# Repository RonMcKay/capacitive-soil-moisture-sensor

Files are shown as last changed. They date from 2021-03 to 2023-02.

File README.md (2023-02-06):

<div align="center">

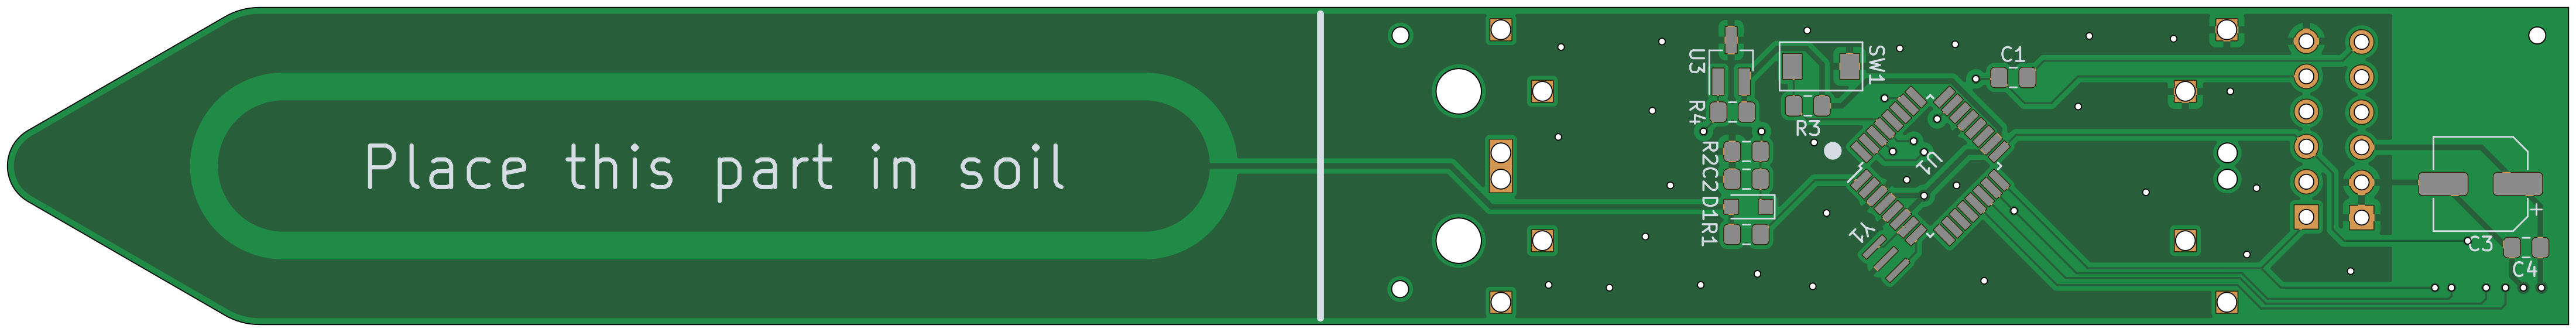
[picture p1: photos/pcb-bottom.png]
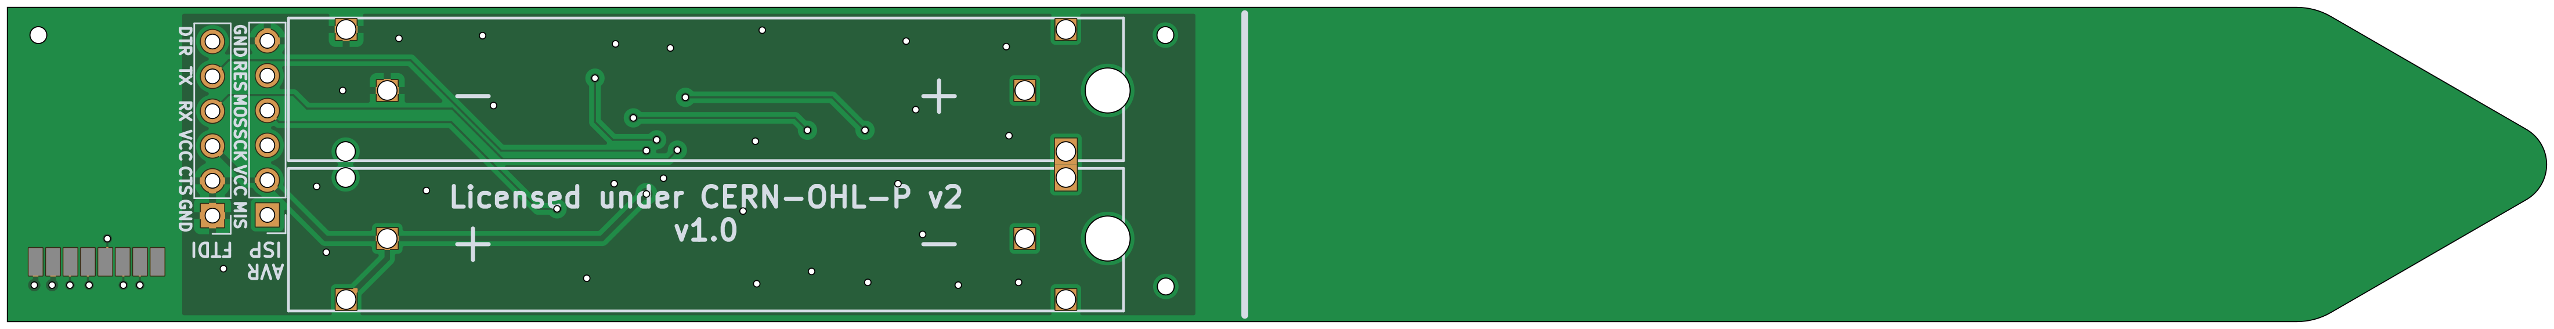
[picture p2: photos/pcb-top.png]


    

# Capacitive Soil Moisture Sensor

</div>

This is a capacitive soil moisture sensor which runs with a standalone ATmega328P and utilizes the [MySensors][1] framework.
It can however be adapted to any other framework that uses 2.4 GHz radio communication with an NRF24L01 if you upload your own code.

A short summary of the features is:
* Runs on 2 AAA batteries
* Sleeping current of 8uA (approx. 10 years of battery life under optimal conditions)
* Uses an NRF24L01 radio module for communication
* Utilizes an ATSHA204A for secure message signing (optional)
* A sensor value range of approximately 400 (from air to water)
* External 8MHz resonator for better temperature stability than the internal oscillator
* All SMD components (except the NRF24L01 radio) on one side of the pcb
* FTDI and AVR ISP connector for programming and bootloader burning
* 3D printable case

**Note: Take care when inserting the batteries as there is no reverse polarity protection on this board. Also check the pin assignment of the FTDI and AVR ISP headers as these might be non standard to save some space.**

# Table of Contents

- [Getting Started](#getting-started)
    - [Requirements](#requirements)
- [Hardware](#hardware)
    - [PCB Production](#pcb-production)
    - [Assembly](#assembly)
    - [Case](#case)
- [Software](#software)
    - [Calibration](#calibration)
- [Future Improvements](#future-improvements)
- [Contributing](#contributing)
- [License](#license)
- [Special Thanks to](#special-thanks-to)
- [Photos](#photos)

# Getting Started

If you want to work on the repository you just have to run:

    git clone --recurse-submodules https://github.com/RonMcKay/capacitive-soil-moisture-sensor

The PCB design is done in KiCad 6. You are pretty much good to go if you open the project with KiCad.

For programming and burning the bootloader I use [Visual Studio Code](https://code.visualstudio.com/)
together with [PlatformIO](https://platformio.org/) and [MiniCore](https://github.com/MCUdude/MiniCore)
(which is already included in the platform io plugin for vs code).

You can generate production/documentation files and run ERC/DRC tests by running `make` in the root directory. All production files are then placed under the hardware directory. The Makefile utilizes [docker](https://www.docker.com/) containers so you should have docker installed.

## Requirements

When working on the project you need the following installed locally and available in the development environment:

- Docker (for generating documentation and production files)
- KiCad 6 (for working on the PCB)
- Openscad (for generating the case)

# Hardware

## PCB Production

In recent years the DIY PCB industry segment has been growing and thus there are numerous options to quite easily order your boards online for low prices. Just download the Gerber-files from the [release page](https://github.com/RonMcKay/capacitive-soil-moisture-sensor/releases) or clone the repository and generate them yourself by running `make`.

## Assembly

For the assembly of your boards there are currently no SMT assembly files supplied with the release, although there are pick and place files for JLCPCB generated by `make` they are not yet optimized or tested, so use them at your own risk. For manual assembly you can find the BOM attached to the release as well as a nice interactive HTML BOM which eases component placement. You only need to take care that the two battery holders which are closest to the radio module do not touch each other as this would cause a short. To be really safe you can bend them away from each other.

**Note:** The ATSHA204A on the board is an optional component. If you do not want to assemble the board with it, you can leave it away together with the accompanying resistor.

## Case

You can find the STL files for a case attached to the release. If you want to tweak the tolerances for your printer or add additional features like printed on version or venting holes you can edit the `hardware/case/case.scad` file and generate the STLs by yourself by running `make case` in the root directory of the repository. The STL files are then placed under `hardware/case`.

# Software

## Calibration

The minimum (air) and maximum (water) sensor values need to be calibrated. For this, get a glass of water and flash the sensor with `#define CALIBRATION_MODE`. While reading out the log messages of the sensor, note down the sensor values for air and submerged in water. Change `AIR_SENSOR_VALUE` and `WATER_SENSOR_VALUE` accordingly and reflash the sensor after commenting out `#define CALIBRATION_MODE`. Your soil moisture sensor is now ready for operation.

# Future Improvements

Here is a list of possible future improvements that might be worth looking into:

* Make the sensor more compact by using a single AA/AAA battery together with a voltage booster
* Changing out the ATmega328P and the NRF24L01 for an NRF52.
* Some temperature readings of the soil would be awesome, like an SMD thermistor or something similar at the tip of the sensor.

Any contributions are highly welcome and I am happy to discuss remarks in the [github discussion section](https://github.com/RonMcKay/capacitive-soil-moisture-sensor/discussions).

# Contributing

I am happy to discuss and accept improvements on the project. Please make all your pull-requests against `master`. It is also a good idea to discuss your planned changes in the [github discussion section](https://github.com/RonMcKay/capacitive-soil-moisture-sensor/discussions) to avoid unnecessary work.

# License

This project is licensed under the CERN-OHL-P v2

# Special Thanks to

* [MySensors Team][1], which made me start creating my own IoT hardware
* miceuz, for his [long writeup](https://wemakethings.net/2012/09/26/capacitance_measurement/) of how capacitive soil moisture sensing is working
* Ken Shirriff, who's post about the [secrets of arduino PWM](http://www.righto.com/2009/07/secrets-of-arduino-pwm.html) made me understand the topic to a certain extend
* Everyone out there who is producing open source hardware and/or guides explaining the topic, which makes the diy electronics topic more accessible

P.S.: The sensor on the photos is only a prototype where I accidentally soldered some wrong value capacitor and forgot a capacitor for the FTDI connector. These are however already fixed in the pcb design.

# Photos

<div align="center">

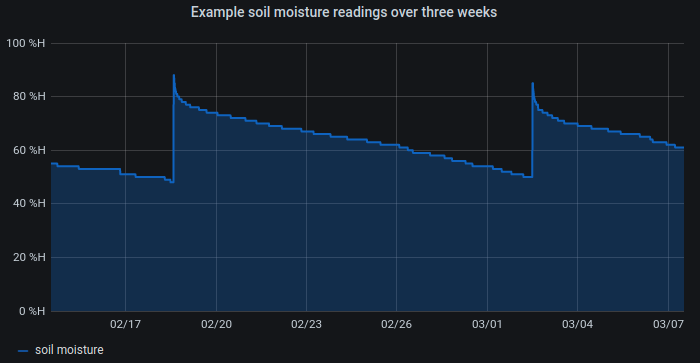
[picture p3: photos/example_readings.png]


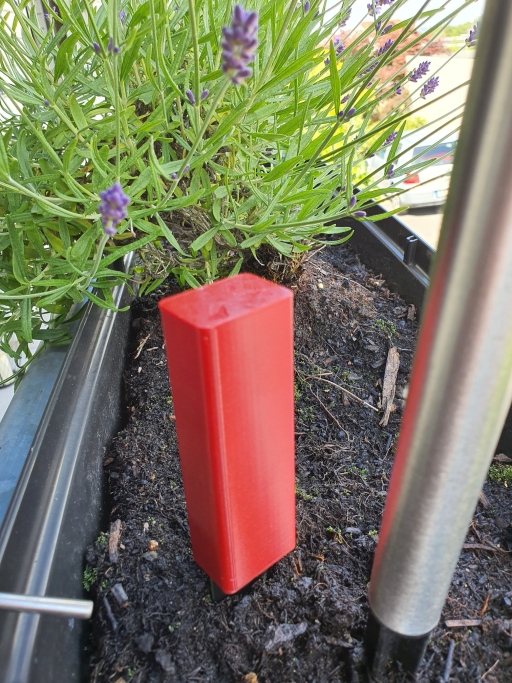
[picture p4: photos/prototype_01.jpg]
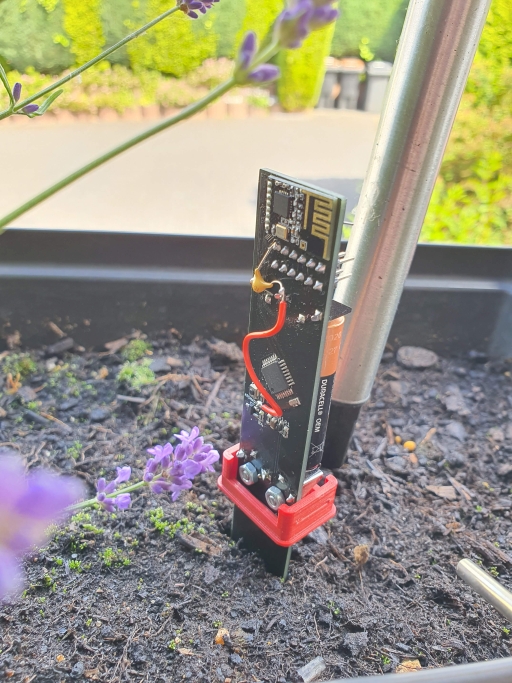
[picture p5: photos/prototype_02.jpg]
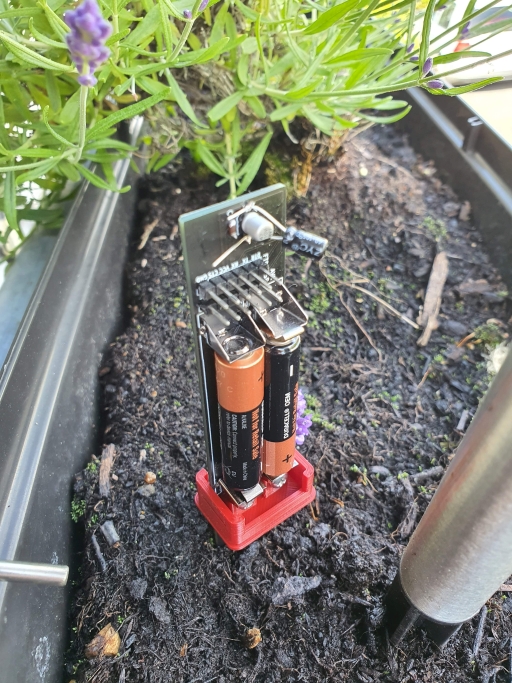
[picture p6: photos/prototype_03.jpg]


[1]: https://www.mysensors.org

</div>

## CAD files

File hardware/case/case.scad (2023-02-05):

$fn=50;

// General
part="all";
release_version="";

// Tolerances
tol=0.15;  // Tolerance for all measurements that need to fit, like screw hole diameter, PCB thickness, etc...
press_fit_tol=0.1;  // Tolerance between the shell and the base

// Wall thicknesses
wall_thickness=0.9;
base_thickness=1.2;

// Text
text_depth=0.5;

// Venting holes
venting_holes=false;
venting_hole_count=5;
venting_hole_dia=2;

// Case dimensions
height=82;  // height of the hole case measured from the center of the mounting screw holes
rim_thickness=2;
rim_height=10;

// Hardware
screw_hole_dia=3;
screw_hole_center_to_post_top = 3.5;
screw_length=10;
nut_thickness=2.4;

// PCB Settings
pcb_thickness=1.6;
pcb_top_depth=10.5;  // space in the case on the top side of the pcb
pcb_bottom_depth=max(2.5, nut_thickness);  // space in the case on the bottom side of the pcb
pcb_width=23.1;
mount_center_from_edge_1=6.1;  // distance to center of left mounting hole when viewed from the top
mount_center_from_edge_2=6.1;  // distance to center of right mounting hole when viewed from the top

// Mounting posts
post_width = 8.3;  // width of the mounting posts
post_height = 10;  // height of the mounting posts
post_depth = max(5, screw_length - pcb_bottom_depth - pcb_thickness - 2 * tol);

// Miscellaneous
fillet_radius=3;

// helper variables
inner_width=pcb_width + 2 * tol;
inner_depth=pcb_top_depth + pcb_bottom_depth + pcb_thickness + 2 * tol;
total_width=inner_width + 2 * wall_thickness + 2 * press_fit_tol + 2 * rim_thickness;
total_depth=inner_depth + 2 * wall_thickness + 2 * press_fit_tol + 2 * rim_thickness;
total_shell_height=height + (post_height - screw_hole_center_to_post_top);

// Edge for the interlocking between shell and base
lock_edge_depth=0.4;
lock_edge_length=inner_depth + 2 * rim_thickness - 2 * (fillet_radius - wall_thickness + press_fit_tol) - 3;

// Locking Edge
module lock_edge(depth=lock_edge_depth, length=lock_edge_length){
    translate([0, -length / 2, depth]) rotate([-90, 0, 0]) linear_extrude(length)
        polygon(points = [[0,0], [depth, depth], [0, 2 * depth]]);
}

// Mount Post
// `pos` is center of bottom front edge
module mounting_post(
    pos=[0, 0, 0],
    width=post_width,
    depth=post_depth,
    height=post_height,
){
    translate(pos - [width / 2, 0, 0])
        difference(){
            cube([width, depth, height]);
            translate([width / 2, -tol, height - screw_hole_center_to_post_top])
                rotate([-90, 0, 0])
                    cylinder(h=depth + 2 * tol, d=screw_hole_dia + 2 * tol);
        };
}

// Base
if(part == "base" || part == "all"){
    difference(){
        union(){
            difference(){
                linear_extrude(base_thickness) difference(){
                    offset(r=fillet_radius) offset(r=-fillet_radius)
                        square(
                                [
                                    total_width,
                                    total_depth,
                                ],
                                center=true
                            );
                        translate([0, wall_thickness + press_fit_tol + rim_thickness + pcb_bottom_depth])
                            translate([0, -total_depth / 2, 0])
                                translate([0, (pcb_thickness + 2 * tol) / 2])
                                    square([pcb_width + 2 * tol, pcb_thickness + 2 * tol], center=true);
                };
                translate([0, total_depth / 2 - (wall_thickness + press_fit_tol + rim_thickness + pcb_top_depth) / 2, text_depth]) rotate([180, 0, 0])
                    linear_extrude(text_depth + 0.1) text(text=release_version, size=max(pcb_top_depth - 4, 4), halign="center", valign="center");
            };
            // Rim
            translate([0, 0, base_thickness])
                difference(){
                    linear_extrude(rim_height)
                        difference(){
                            offset(r=(fillet_radius - wall_thickness + press_fit_tol)) offset(r=-(fillet_radius - wall_thickness + press_fit_tol))
                                square([inner_width + 2 * rim_thickness, inner_depth + 2 * rim_thickness], center=true);
                            square([inner_width, inner_depth], center=true);
                        };
                    translate([0, 0, max(post_height - screw_hole_center_to_post_top - 3.5, 0)])
                        linear_extrude(height=screw_hole_center_to_post_top + 3.5 + 0.1)
                            square(
                                [
                                    pcb_width - ((mount_center_from_edge_1 - post_width / 2) + (mount_center_from_edge_2 - post_width / 2)) + 1,
                                    inner_depth + 2 * rim_thickness + 0.1
                                ],
                                center=true
                            );
                    translate([inner_width / 2 + rim_thickness, 0, rim_height / 2]) rotate([0, 180, 0]) lock_edge(depth=lock_edge_depth + tol);
                    translate([- (inner_width / 2 + rim_thickness), 0, rim_height / 2]) lock_edge(depth=lock_edge_depth + tol);
                }
            mounting_post([
                -pcb_width / 2 + mount_center_from_edge_1,
                -total_depth / 2 + wall_thickness + press_fit_tol + rim_thickness + pcb_bottom_depth + pcb_thickness + 2 * tol,
                base_thickness
            ]);
            mounting_post([
                pcb_width / 2 - mount_center_from_edge_2,
                -total_depth / 2 + wall_thickness + press_fit_tol + rim_thickness + pcb_bottom_depth + pcb_thickness + 2 * tol,
                base_thickness
            ]);
        };
        if(venting_holes){
            translate([-inner_width / 2, total_depth / 2 - wall_thickness - press_fit_tol - rim_thickness - (pcb_top_depth - post_depth) / 2, 0]) linear_extrude(base_thickness)
                for (i = [1:venting_hole_count]) {
                    translate([inner_width / (venting_hole_count + 1) * i, 0, 0]) circle(d=venting_hole_dia);
                }
        }
    };
}



// Shell
if(part == "shell" || part == "all"){
    translate([total_width + 1, 0, base_thickness + wall_thickness + tol + total_shell_height])
        rotate([180, 0, 0])
            difference(){
                union(){
                    translate([0, 0, base_thickness + tol]) union(){
                        linear_extrude(total_shell_height) difference(){
                            offset(r=fillet_radius) offset(r=-fillet_radius) square([total_width, total_depth], center=true);
                            offset(r=(fillet_radius - wall_thickness)) offset(r=-(fillet_radius - wall_thickness))
                                square([total_width - 2 * wall_thickness, total_depth - 2 * wall_thickness], center=true);
                        };
                        translate([-inner_width / 2 - rim_thickness - press_fit_tol, 0, rim_height / 2 + tol])
                            lock_edge(length=lock_edge_length - 2 * tol);
                        translate([+inner_width / 2 + rim_thickness + press_fit_tol, 0, rim_height / 2 + tol]) rotate([0, 180, 0])
                            lock_edge(length=lock_edge_length - 2 * tol);
                    };
                    translate([0, 0, base_thickness + tol + total_shell_height])
                        linear_extrude(wall_thickness)
                            offset(r=fillet_radius) offset(r=-fillet_radius) square([total_width, total_depth], center=true);
                };
                translate(
                    [
                        0,
                        0,
                        base_thickness + tol + total_shell_height + min(text_depth, wall_thickness / 2)
                    ]
                )
                    rotate([180, 0, 0])
                        linear_extrude(text_depth + 0.1) text(text=release_version, size=pcb_top_depth - 3, halign="center", valign="center");
            };
}

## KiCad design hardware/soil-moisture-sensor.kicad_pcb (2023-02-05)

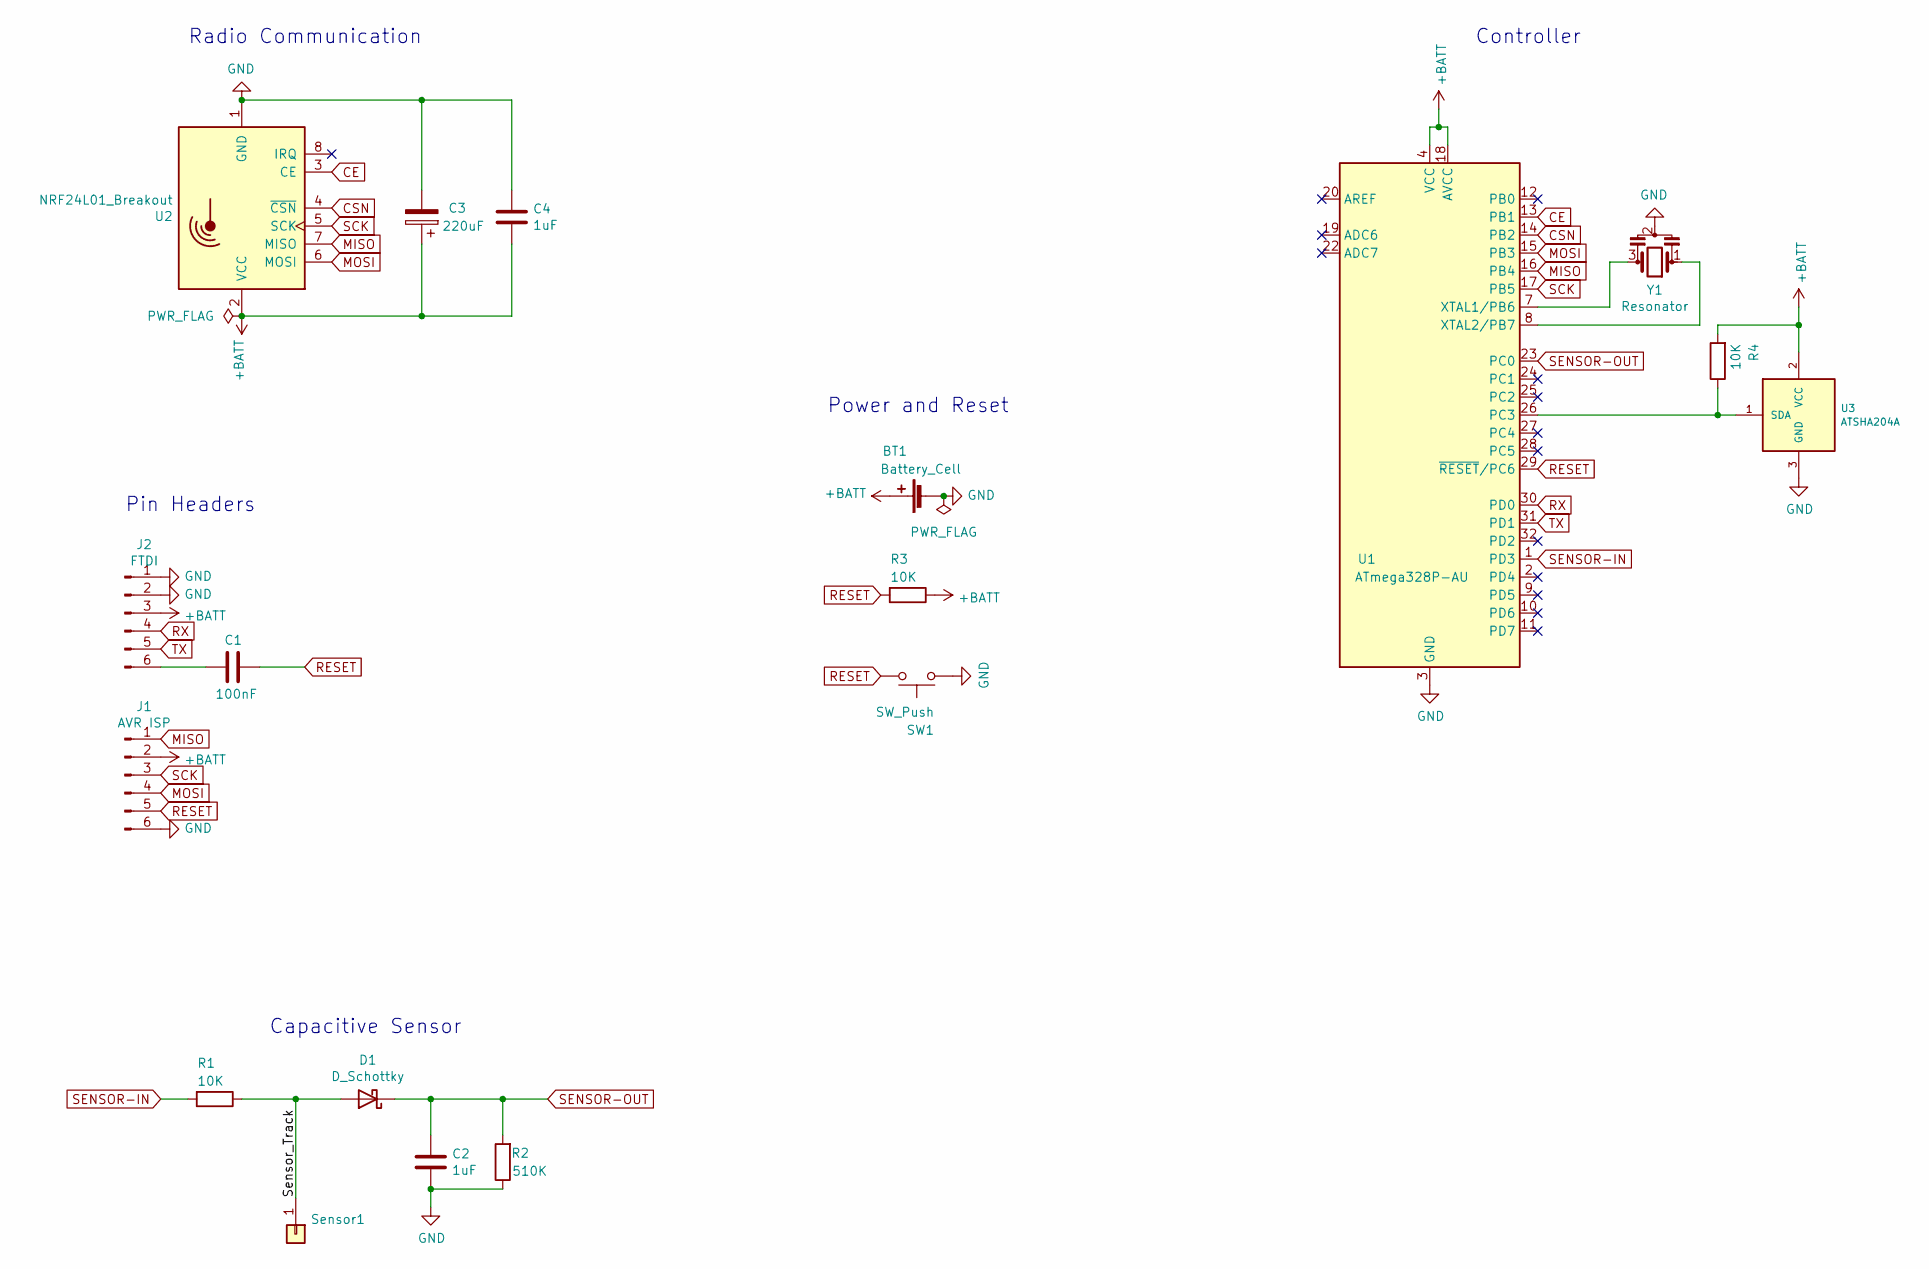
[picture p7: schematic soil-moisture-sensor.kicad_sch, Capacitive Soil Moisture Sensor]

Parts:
BT1: Battery_Cell; BatteryHolder_Keystone_597_591_2AAA_3V
C1: 100nF; C_0805_2012Metric_Pad1.15x1.40mm_HandSolder; LCSC C49678
C2, C4: 1uF; C_0805_2012Metric_Pad1.15x1.40mm_HandSolder; LCSC C28323
C3: 220uF; CP_Elec_6.3x7.7; LCSC C127327
D1: D_Schottky; D_SOD-323_HandSoldering; LCSC C154819
J1: AVR ISP; PinHeader_1x06_P2.54mm_Vertical; LCSC C2833331
J2: FTDI; PinHeader_1x06_P2.54mm_Vertical; LCSC C2833331
R1, R3, R4: 10K; R_0805_2012Metric_Pad1.15x1.40mm_HandSolder; LCSC C17414
R2: 510K; R_0805_2012Metric_Pad1.15x1.40mm_HandSolder; LCSC C17733
SW1: SW_Push; Button_2P_TS-1088-AR02016; LCSC C720477
Sensor1: Conn_01x01; Capacitive_Soil_Moisture_Sensor
U1: ATmega328P-AU; TQFP-32_7x7mm_P0.8mm; LCSC C14877
U2: NRF24L01_Breakout; NRF24L01-SMD
U3: ATSHA204A; SOT-23_Handsoldering; LCSC C34377
Y1: Resonator; ceramik_resonator_murata_CSTCE8M00G52-R0; LCSC C907975

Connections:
+BATT: BT1.1 (+), C3.1, C4.2, J1.2, J2.3, R3.1, R4.2, U1.4 (VCC), U1.6 (VCC), U1.18 (AVCC), U2.2 (VCC), U3.2 (VCC)
/Sensor_Track: D1.2 (A), R1.1, Sensor1.1
CE: U1.13 (PB1), U2.3 (CE)
CSN: U1.14 (PB2), U2.4 (~CSN)
GND: BT1.2 (-), C2.2, C3.2, C4.1, J1.6, J2.1, J2.2, R2.1, SW1.1, U1.3 (GND), U1.5 (GND), U1.21 (GND), U2.1 (GND), U3.3 (GND), Y1.2
MISO: J1.1, U1.16 (PB4), U2.7 (MISO)
MOSI: J1.4, U1.15 (PB3), U2.6 (MOSI)
unnamed: C1.2, J2.6
unnamed: R4.1, U1.26 (PC3), U3.1 (SDA)
unnamed: U1.7 (XTAL1/PB6), Y1.3
unnamed: U1.8 (XTAL2/PB7), Y1.1
RESET: C1.1, J1.5, R3.2, SW1.2, U1.29 (~RESET/PC6)
RX: J2.4, U1.30 (PD0)
SCK: J1.3, U1.17 (PB5), U2.5 (SCK)
SENSOR-IN: R1.2, U1.1 (PD3)
SENSOR-OUT: C2.1, D1.1 (K), R2.2, U1.23 (PC0)
TX: J2.5, U1.31 (PD1)

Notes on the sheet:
Capacitive Sensor
Power and Reset
Controller
Radio Communication
Pin Headers

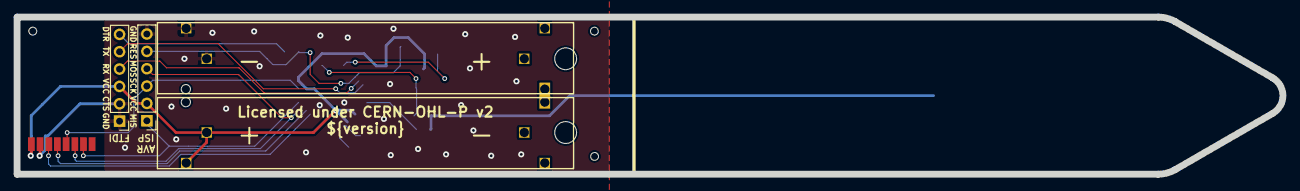
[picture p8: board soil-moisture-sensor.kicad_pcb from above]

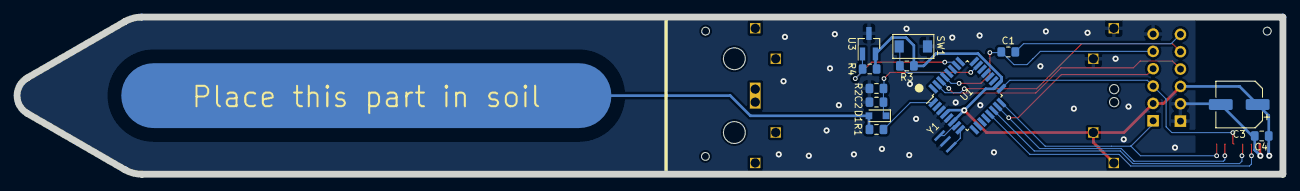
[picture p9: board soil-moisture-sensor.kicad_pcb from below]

Board: 2 copper layers, 185.3 x 23.0 mm, 18 parts (14 on the bottom side), 17 nets.

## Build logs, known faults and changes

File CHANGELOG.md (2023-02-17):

# Changelog
All notable changes to this project will be documented in this file.

The format is based on [Keep a Changelog](https://keepachangelog.com/en/1.0.0/).

## 1.0.1 (2021-12-01)

### 🐛 Fixes

- Fixed `MY_DEBUG` in code with debug messages never being hit

### 📔 Documentation

- Restricted version number on the PCB to '**major.minor**'

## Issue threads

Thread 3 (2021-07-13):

without ATSHA204A

garudaonekh, 2021-07-13:
hi, can i use it without this ATSHA204A?

adfx, 2021-07-13:
For sure you can. Maybe you need to adopt the code a bit

RonMcKay, 2021-07-14:
Yes, you can do that without a problem.
If you are using the MySensors framework just comment out `#define MY_SIGNING_ATSHA204` in the code and you can leave away the ATSHA204A as well as the accompanying resistor.
You can also use `#define MY_SIGNING_SOFT` for software signing.

Please be aware that sensors that are placed outside and accessible to others **can be a security risk** when not handled properly. You can read more about that topic [here](https://www.mysensors.org/about/signing).

Closed 2021-07-14.

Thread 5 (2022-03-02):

Make sensor including case more compact by using single AAA + voltage booster

RonMcKay, 2022-03-02:
The sensor including the case is too bulky. The ability to use 2x AAA batteries is nice but it would be way more compact with using a single AAA battery. For this to work there has to be a voltage booster. This will inevitably lead to more components but voltage boosters are quite cheap and usually there are no more than 3-4 additional SMD components.

RonMcKay, 2022-10-20:
Closing this, because with the current iteration of the case (#9) it will be hard to make the case more compact. Additionally, adding a voltage booster increases component cost and count.

Focus should be put on increasing the water proofing of the case.

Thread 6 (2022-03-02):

Create OpenSCAD file for the case

RonMcKay, 2022-03-02:
In order to be able to version control the case and enable other contributors to work on it there should be an OpenSCAD version of it.

Additionally the print time and material consumption of the case should be reduced.

RonMcKay, 2022-06-12:
Closed by #9.

Closed 2022-06-12.

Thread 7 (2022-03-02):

Improve workflow of calibrating the sensor values

RonMcKay, 2022-03-02:
Currently it is quite cumbersome to calibrate the raw sensor values as one has to upload the sketch in `CALIBRATION_MODE` first, note the values in air and water, update the sketch and reupload it to the sensor. When trying to deploy a lot of these sensors this takes a lot of time. A nicer way would be to include a second button and a LED which could drive a small "calibration interface".

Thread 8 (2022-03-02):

Make creation of production files scriptable

RonMcKay, 2022-03-02:
Production files are currently generated by hand. This is error prone and not fully reproducible.
A nice solution for this is to intregrate [KiBot](https://github.com/INTI-CMNB/KiBot) together with a Makefile. This would make it much easier to generate a suite of production files, including the assembly files which are currently not available.
Going further down the road this should also be implemented as a GitHub action to automatically generate all production files for new releases.

Closed 2022-04-16.

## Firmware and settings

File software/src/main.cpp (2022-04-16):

#include <Arduino.h>

// #define MY_DEBUG
// #define MY_DEBUG_VERBOSE_SIGNING
// #define CALIBRATION_MODE

// Soft signing
// #define MY_SIGNING_SOFT
// #define MY_SIGNING_SOFT_RANDOMSEED_PIN 0
#define MY_SIGNING_ATSHA204

// Defining Node ID
#define MY_NODE_ID 1

#define MY_BAUD_RATE 9600

// Enable and select radio type attached
#define MY_RADIO_RF24

#include <MySensors.h>

#define SENSOR_ID 0

#define MESSAGEWAIT 50      // ms to wait between each send message
#define SLEEP_IN_MS 1800000 // ms to sleep between sensor measurements
#define MAX_RESEND_COUNT 3  // if a send message got no acknowledge message the sensor tries to send the message again but at most MAX_RESEND_COUNT times. Set to 1 for no resending.

#define PWM_WAIT_MS 200 // amount of ms to wait for the pwm signal to start up and the sensor values to settle

// Needed for conversion from raw sensor values to percentages
// calibrate in air and a glass of water with CALIBRATION_MODE and serial monitor
#define AIR_SENSOR_VALUE 152
#define WATER_SENSOR_VALUE 556

#define ABSOLUTE_CHANGE 4 // Sensor value will only be send if the absolute change compared to the last measured raw sensor value is at least this

// Values for battery measurements
const float VccMin = 2.4; // 8 MHz arduino runs reliably down to 2.4V (see datasheet)
const float VccMax = 3;   // 2 AAA = 3V

// these are used for checking if the current measurement has changed compared to the last one
int oldBatLevel;
int oldSensorVal;

int n_reads = 1;                // number of measurements to average over. Multiple measurements might increase repeatability but also increase battery consumption.
int wait_between_reads_ms = 20; // amount of ms to wait between multiple reads

MyMessage msgSensor(SENSOR_ID, V_HUM);

void presentation()
{
  // Send the sketch version information to the gateway and Controller
  sendSketchInfo("Capacitive Soil Moisture Sensor", "1.0");
  sleep(MESSAGEWAIT);

  present(SENSOR_ID, S_HUM);
  sleep(MESSAGEWAIT);
}

void startPWMSignal()
{
  TCCR2A = (1 << COM2B1) | (1 << WGM21) | (1 << WGM20); // Clear OC2B on Compare Match, Mode 7 - Fast PWM
  TCCR2B = (1 << WGM22) | (1 << CS20);                  // no clock prescaling

  // Note: Somehow the software and/or hardware configuration did not allow setting a lower OCR2A value to increase the frequency.
  // Each time I tried increasing the frequency while keeping the duty cycle at 50 percent the output of the capacitive probe was a constant regardless of the surrounding material.
  // If you know what is going on here I would be more than happy if you could shed some light on it in the GitHub discussion area.

  OCR2A = 7; // OCR2A is set as top so clock is divided by 8 -> 1 MHz output frequency max.
  OCR2B = 3; // 50 percent duty cycle
}

void stopPWMSignal()
{
  // Set the timers back to normal
  TCCR2A = 0;
  TCCR2B = 0;
}

void setup()
{
  pinMode(3, OUTPUT);
  pinMode(A0, INPUT);

  oldBatLevel = 200;
  oldSensorVal = -1023;
}

void resendbatterylevel(int batlevel)
{
  int repeat = 0;

  while (repeat < MAX_RESEND_COUNT)
  {
    if (sendBatteryLevel(batlevel))
    {
#ifdef MY_DEBUG
      Serial.print("Battery level send succesfully. Number of tries: ");
      Serial.println(++repeat);
#endif
      break;
    }
    else if (++repeat < MAX_RESEND_COUNT) // only sleep if it is not our last repeat
    {
      sleep(MESSAGEWAIT);
    }
#ifdef MY_DEBUG
    Serial.print("Battery send error ");
    Serial.println(repeat);
#endif
  }
}

void resend(MyMessage &msg)
{
  int repeat = 0;

  while (repeat < MAX_RESEND_COUNT)
  {
    if (send(msg))
    {
#ifdef MY_DEBUG
      Serial.print("Message send succesfully. Number of tries: ");
      Serial.println(++repeat);
#endif
      break;
    }
    else if (++repeat < MAX_RESEND_COUNT) // only sleep if it is not our last repeat
    {
      sleep(MESSAGEWAIT);
    }
#ifdef MY_DEBUG
    Serial.print("Error ");
    Serial.println(repeat);
#endif
  }
}

int read_sensor()
{
  startPWMSignal();
  delay(PWM_WAIT_MS); // let the PWM signal start up and the sensor values settle

  float sensor_value = 0;
  for (int i = 0; i < n_reads; ++i)
  {
    sensor_value += analogRead(A0);

    // only wait for next measurement if it is not the last one
    if (i + 1 < n_reads)
    {
      delay(wait_between_reads_ms);
    }
  }
  sensor_value /= n_reads;

  stopPWMSignal();

  return 1023 - (int)sensor_value;
}

void sendValue()
{
  int sensorVal = read_sensor(); // read raw sensor value
  if (abs(oldSensorVal - sensorVal) >= ABSOLUTE_CHANGE)
  {
    // convert raw sensor value to percent
    sensorVal = map(sensorVal, AIR_SENSOR_VALUE, WATER_SENSOR_VALUE, 0, 100);
    sensorVal = constrain(sensorVal, 0, 100);

    resend(msgSensor.set(sensorVal, 2));
    oldSensorVal = sensorVal;
  }

  int batLevel = map(hwCPUVoltage(), VccMin * 1000, VccMax * 1000, 0, 100); // * 1000, because 'hwCPUVoltage' reads the voltage in millivolts
  batLevel = constrain(batLevel, 0, 100);
  if (batLevel != oldBatLevel)
  {
    resendbatterylevel(batLevel);
    oldBatLevel = batLevel;
  }
}

void loop()
{
#ifndef CALIBRATION_MODE
  sendValue();
  sleep(SLEEP_IN_MS);
#endif

#ifdef CALIBRATION_MODE
  int sensorVal = read_sensor();
  Serial.println(sensorVal);
  wait(500);
#endif
} // end of loop

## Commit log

2021-03-12 Add PCB render images
2021-08-13 Add battery runtime estimation
2021-08-19 Improve thread model of case
    Larger threads for easier printing and shorter screw on.
    [Mount.stl, Shell.stl]
2021-10-30 Add some missing LCSC part numbers and datasheets
    [soil-moisture-sensor.sch]
2021-10-30 Add BOM
2021-10-31 Make foldernames lowercase
    [Mount.stl, Shell.stl]
2021-10-31 Move bom to production folder
2021-10-31 Add version number to silkscreen
    [soil-moisture-sensor.kicad_pcb]
2021-10-31 Update BOM with version number
2021-12-01 Add CALIBRATION_MODE
    MY_DEBUG should be kept seperate from the calibration of the sensor.
    With the previous setup it was not possible to specify MY_DEBUG to debug
    the wireless transmisison of the sensor as the debug statements were never
    reached.
2021-12-01 Add documentation for calibration of the sensor
2021-12-01 Restrict version to major.minor on the PCB
    Also included the CERN-OHL-P v2 on the schematic.
    [soil-moisture-sensor.kicad_pcb, soil-moisture-sensor.sch]
2022-03-07 Remove some unneccesary info from .pro and .sch
    [soil-moisture-sensor.sch]
2022-03-07 Add KiCad cache lib
2022-03-07 Fix wrong LCSC part number
    [soil-moisture-sensor.sch]
2022-03-07 Update footprint of NRF24L01-SMD
    [soil-moisture-sensor.kicad_pcb, soil-moisture-sensor.sch]
2022-03-07 Add config with "rotated" tag
    The +rotated tag will be used for selecting the right components when
    generating the JLCPCB pick and place files.
    [soil-moisture-sensor.sch]
2022-03-07 Change line endings from CRLF to LF
    [soil-moisture-sensor.sch]
2022-03-07 Update courtyard of NRF24L01 footprint
    The courtyard was not a closed shape which caused DRC errors.
    [soil-moisture-sensor.kicad_pcb]
2022-03-10 Make tooling holes virtual components
    [soil-moisture-sensor.kicad_pcb]
2022-03-11 Add %%version%% and %%date%% placeholders
    The '%%version%%' and '%%date%%' placeholders have been added to the
    appropriate locations in the schematic and pcb file. They are
    automatically replaced during a release with the correct version and
    date of the release.
    [soil-moisture-sensor.kicad_pcb, soil-moisture-sensor.sch]
2022-06-12 Compact OpenSCAD case (#9)
    * Remove old case stls
    * Add stl files to .gitignore
    * Add first version of openscad case
    * Add case to Makefile
    * Add possibility to add a version number
    * Add interlocking edge
    * Fix height of shell
    * Add venting hole option and organize variables
    * Update README
    * Integrate generation of case STLs into GH-WF
    * Update photos with new case
    - 56% faster print time
    - 56% less material used
    - Easier to print
    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
    [Mount.stl, Shell.stl, case.scad]
2023-01-22 build(KiBot): Add preflight variable replacement
    [soil-moisture-sensor.kicad_pcb, soil-moisture-sensor.sch]
2023-01-27 Switch PCB Project to Kicad 6 (#13)
    * refactor(KiCad)!: Switch to KiCad 6 file layout
    * fix(PCB): Remove micro tracks
    From the migration to KiCad 6 there were micro tracks producing errors in the
    DRC.
    * build(gitignore): Ignore kicad_pro backup files
    * build: Switch to KiCad 6 text variables
    * build: Use `restore_project` setting instead of copying source files
    * fix: Fix some ERC/DRC warnings
    * docs(README): Update README
    * ci(CI/CD): Change to KiCad 6 action of KiBot for GH workflows
    * docs(CHANGELOG): Update changelog
    [soil-moisture-sensor.kicad_pcb, soil-moisture-sensor.kicad_sch, soil-moisture-sensor.sch]
2023-02-03 Add LCSC part numbers to iBOM (#15)
    ci(BOM): Include LCSC part numbers into ibom
2023-02-04 Automatically update the README header images on new release (#16)
    * build: Generate top and bottom view in png format
    * docs: Update header image with PCB top/bottom render
    * docs(README): Add version badge to README
    * ci: Automatically generate new README header images on release
    * ci: Use GITHUB_TOKEN to generate the changelog
2023-02-05 Switch to master only setup (#18)
    ci: Switch to master only setup

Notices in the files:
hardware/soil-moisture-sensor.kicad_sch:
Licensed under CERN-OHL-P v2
